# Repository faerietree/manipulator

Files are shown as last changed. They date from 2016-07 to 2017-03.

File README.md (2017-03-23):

Robotic Manipulator
===

The pivot of many machines of the world development global village construction set.

Core
---
* scalable (scale up to use for forest work, as crane or defense herc)
* hydraulic (electrical delivered too little payload for DIY heavy duty transmission)

High Level Overview
---

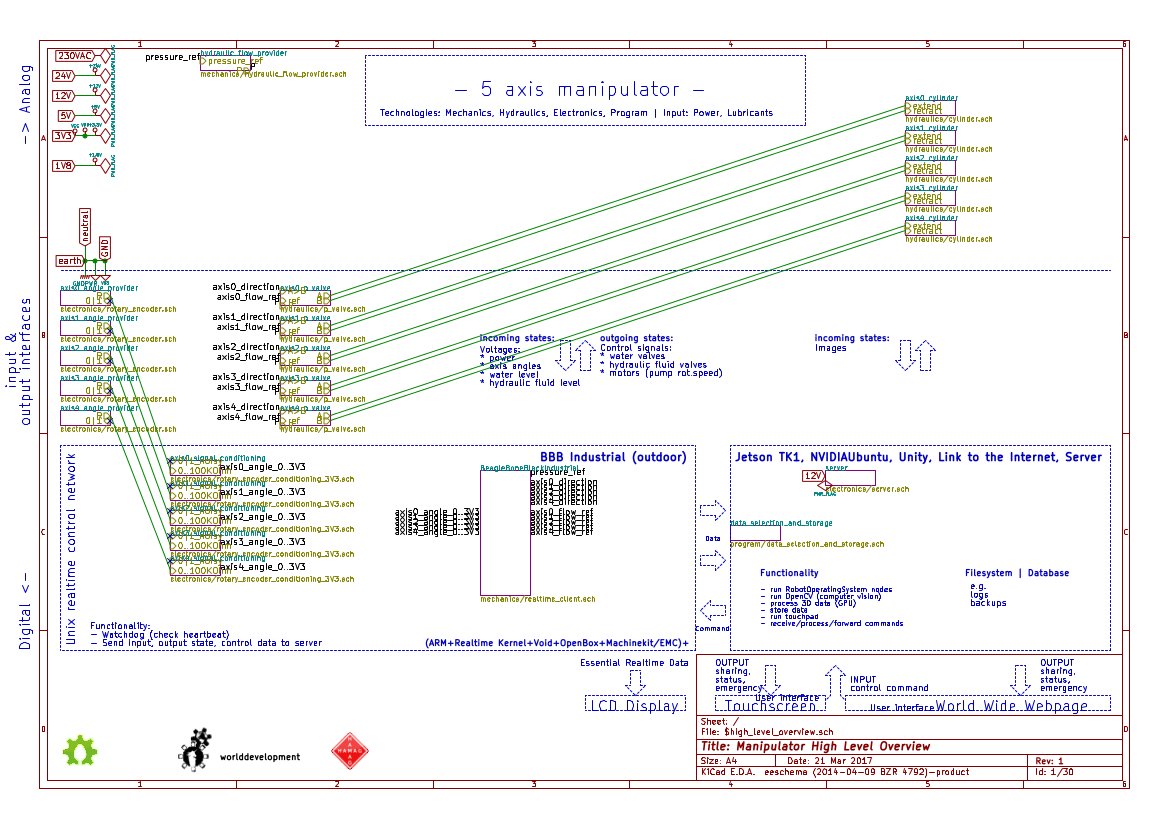
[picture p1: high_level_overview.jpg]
high_level_overview


Developers:
---
worlddevelopment e.V. & other world citizens

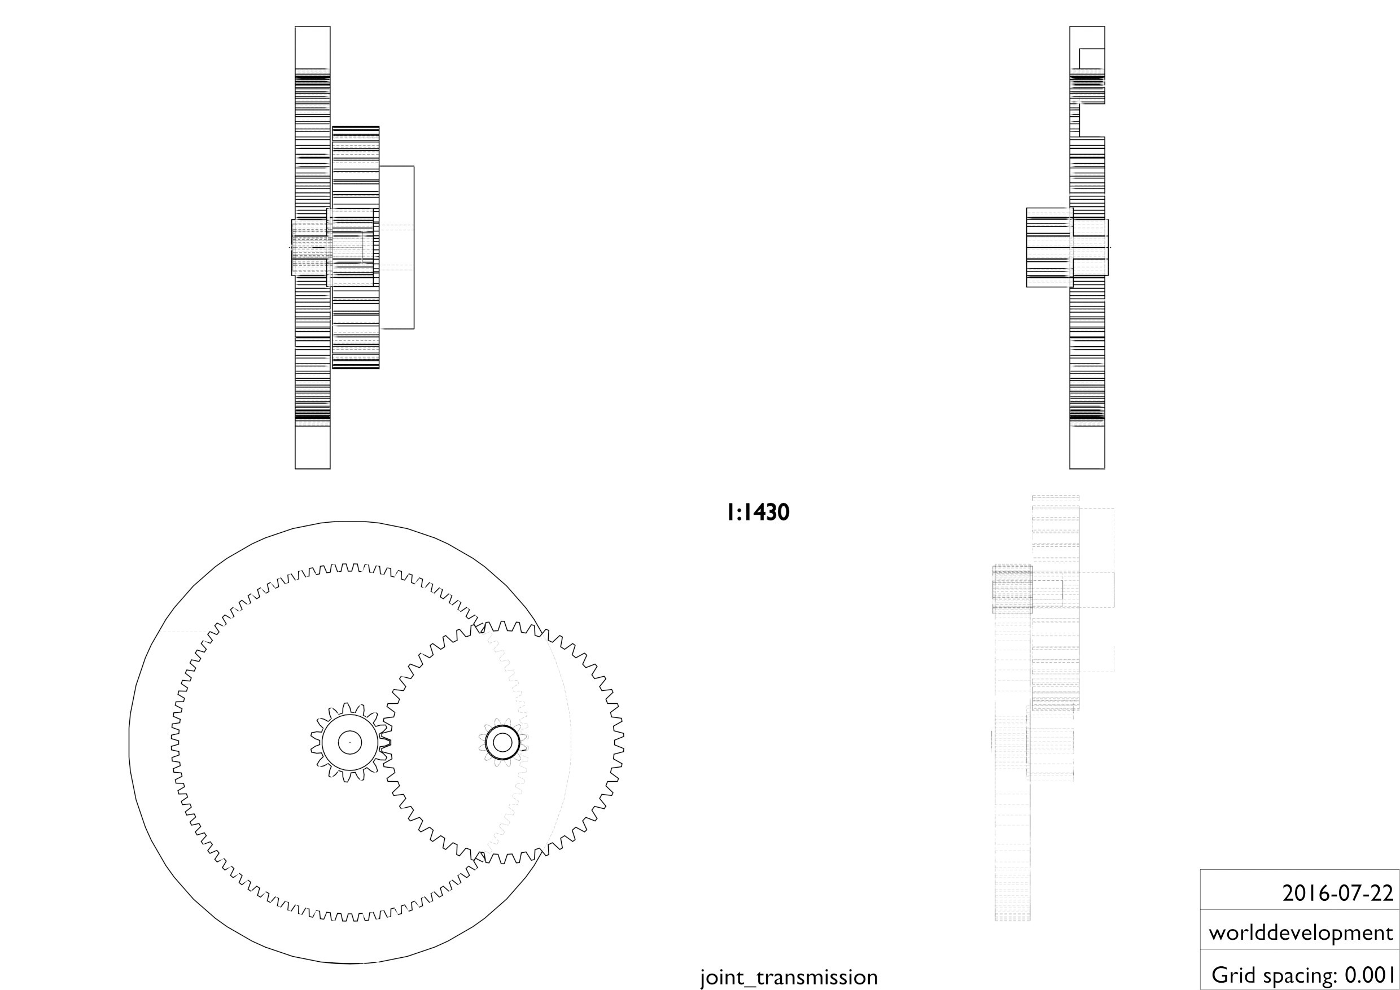
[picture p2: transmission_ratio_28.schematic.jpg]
schematic joint transmission ratio 28


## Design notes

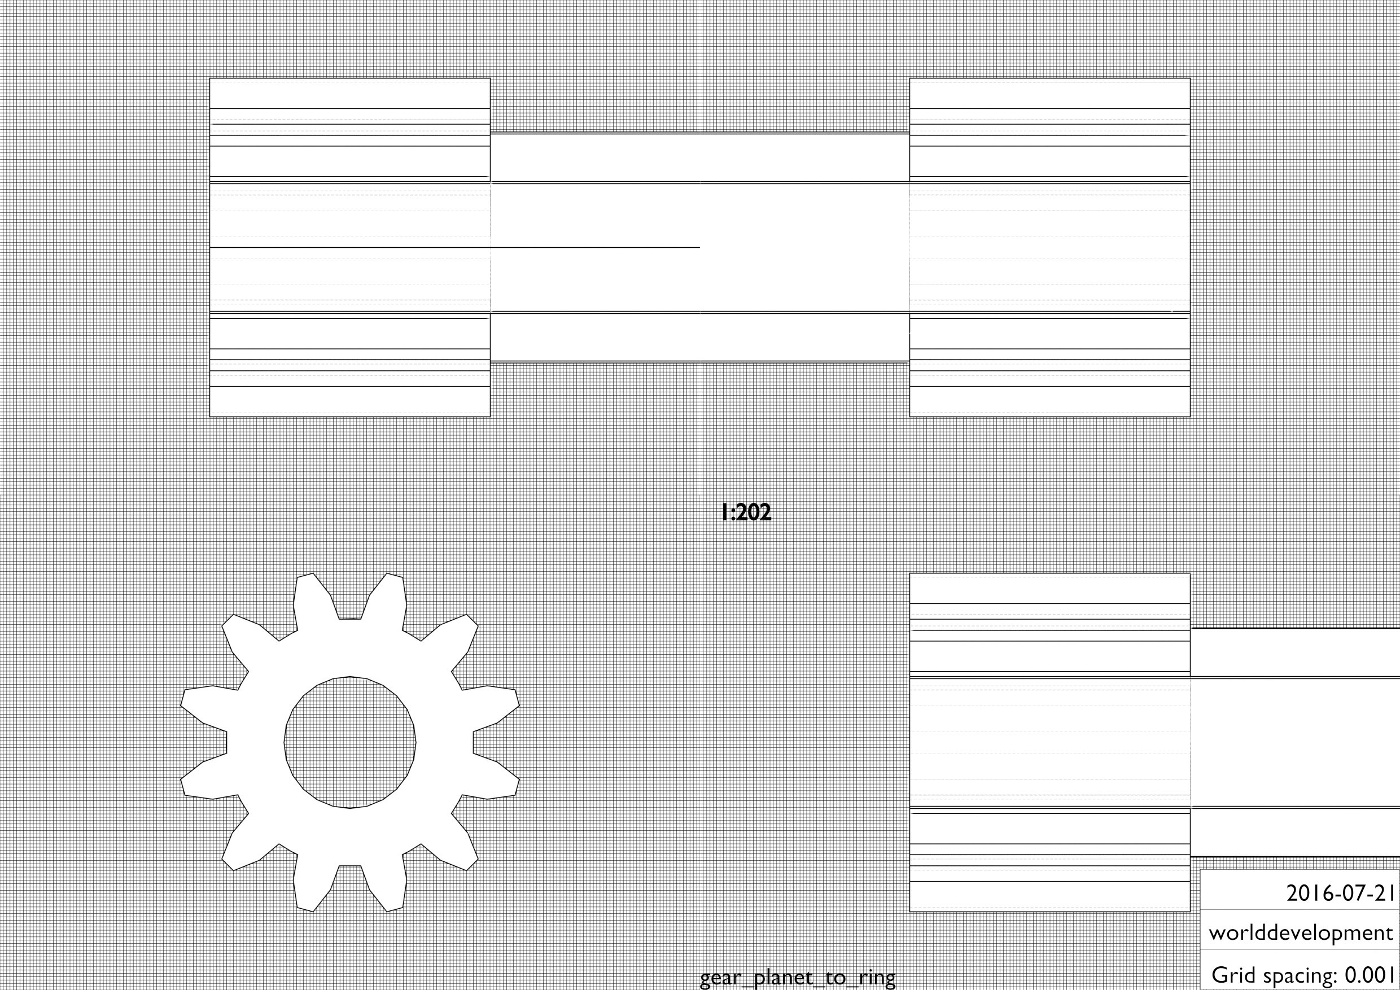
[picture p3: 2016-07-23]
gear_planet_to_ring.schematic.jpg

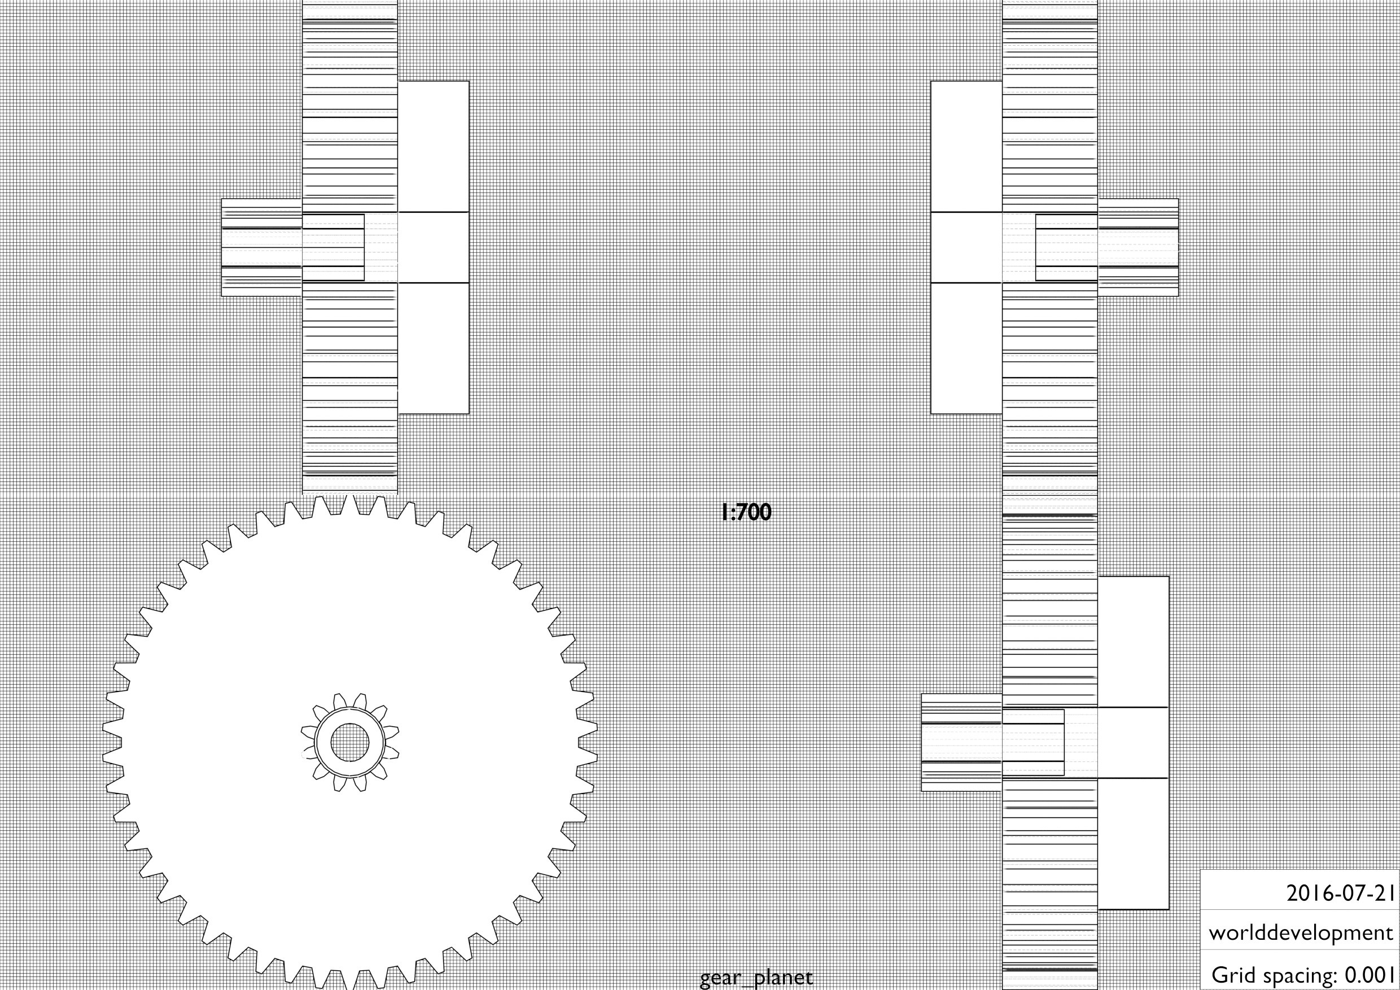
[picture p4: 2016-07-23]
gear_planet.schematic.jpg

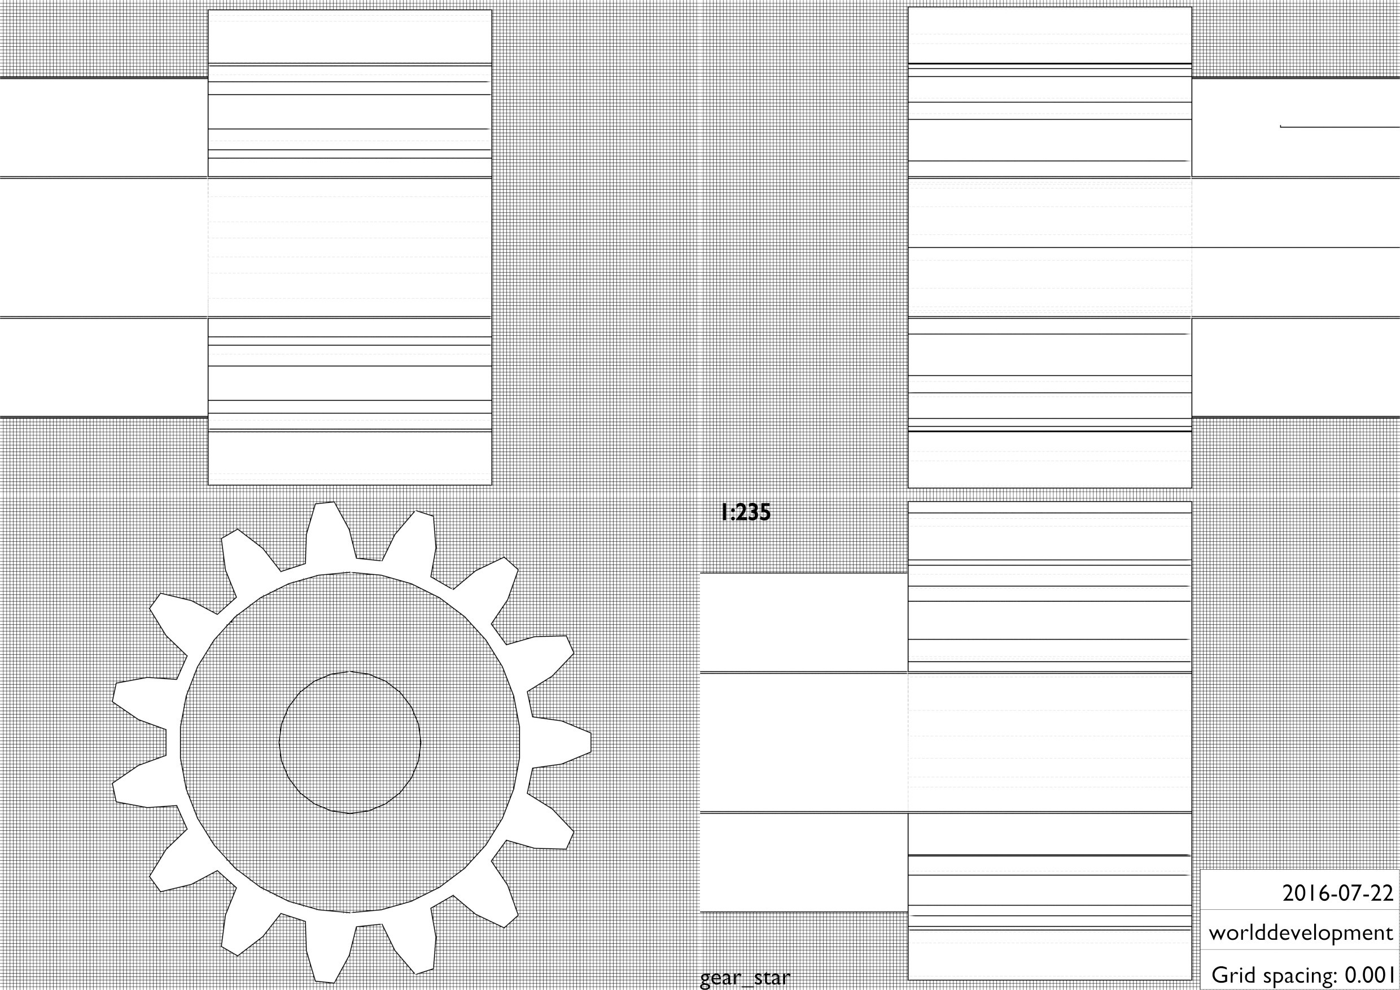
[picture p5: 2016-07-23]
gear_star.schematic.jpg

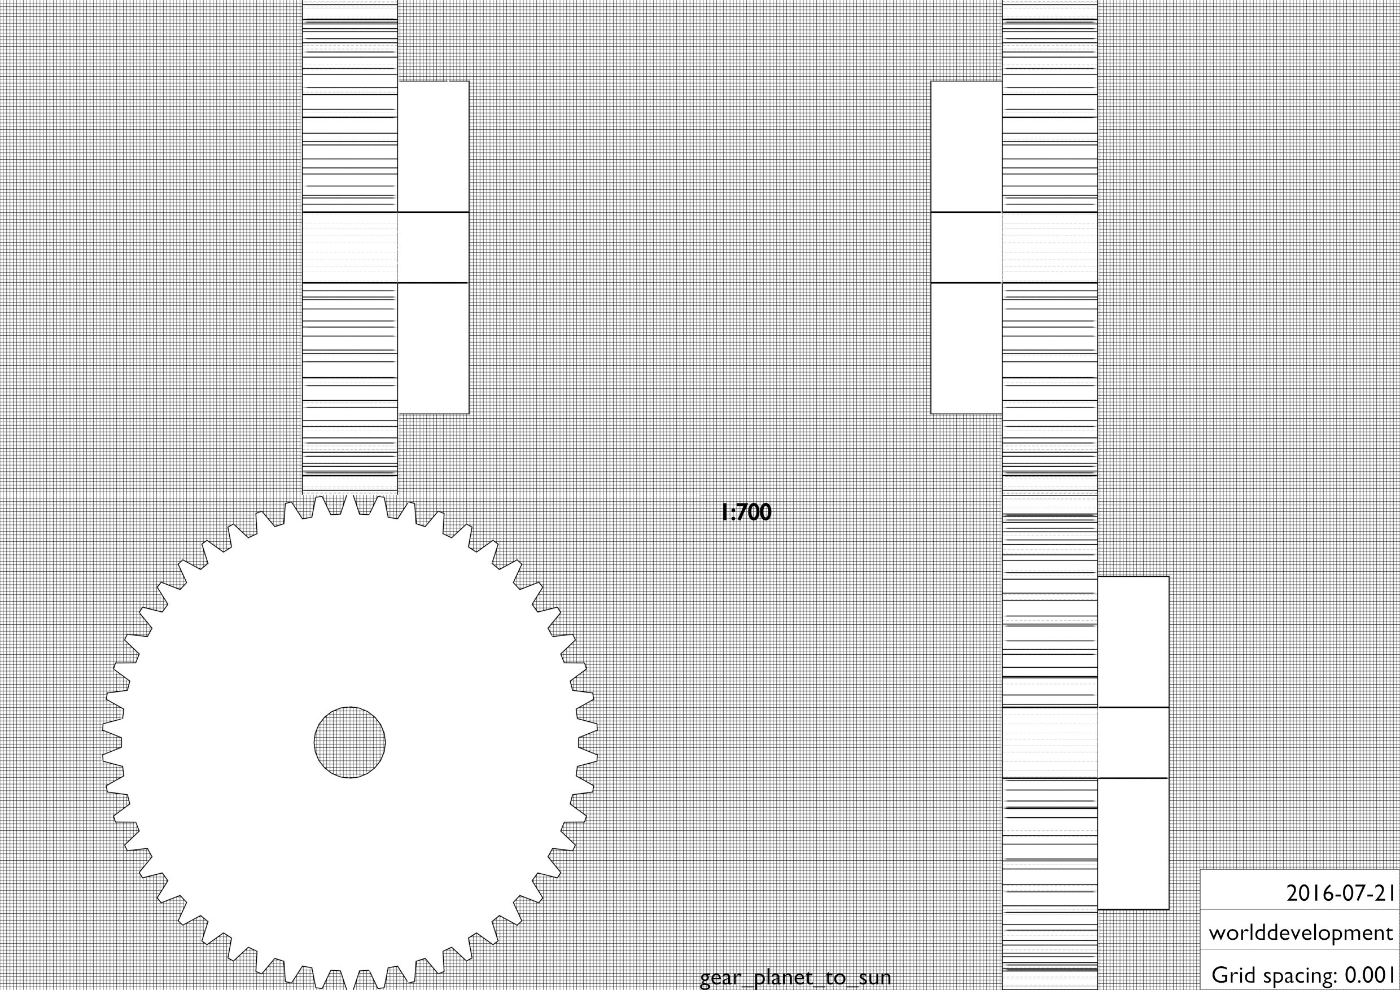
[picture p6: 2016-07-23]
gear_planet_to_sun.schematic.jpg

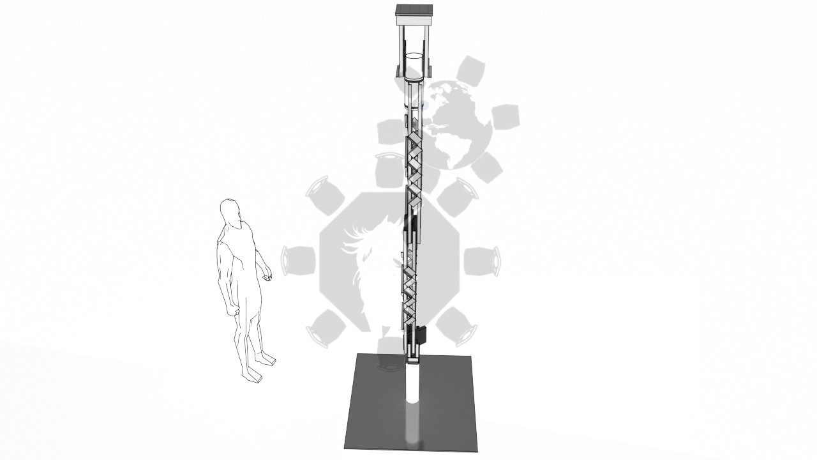
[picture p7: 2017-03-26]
mechanics/manipulator_fountain_pos.jpg

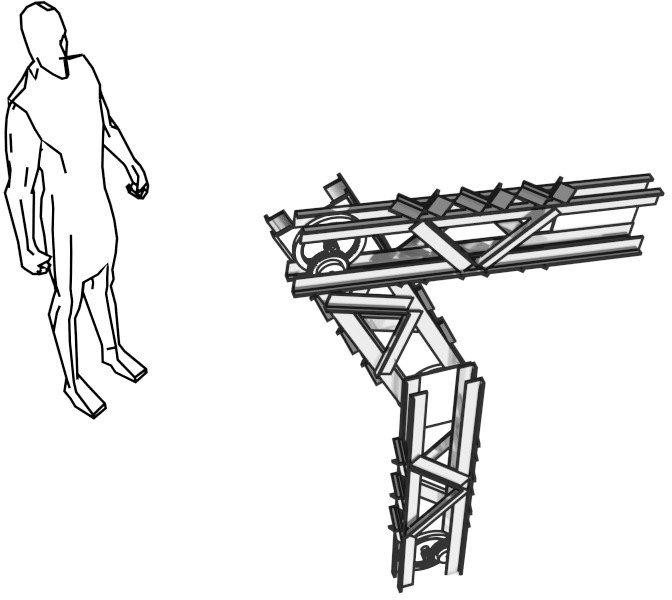
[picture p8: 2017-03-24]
mechanics/manipulator_electric.jpg

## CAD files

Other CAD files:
mechanics/gear.blend
mechanics/gear_pinion.blend
mechanics/gear_ring.blend
mechanics/manipulator.blend
mechanics/motor.blend

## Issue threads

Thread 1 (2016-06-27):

Joint transmission:  Planet gear interfacing ring gear is made of metal instead of plastic leading to erosion.

faerietree, 2016-06-27:
This has the benefit of longer life because this planet gear is in the pinion role leading to more wear because the gear teeth have to more often do more work.

The major disadvantage of it though is that metal to metal contact will lead to immense wear in the shell, i.e. the robotic manipulator links which needs evaluation to check if this makes it the weakest part.

faerietree, 2016-06-27:
* A possible solution is a plastic sheet inbetween the link and the transmission at the corresponding compound gear's side.
* Another idea is to try to source a plastic gear with the same properties at all cost.

Because the manipulator must be as affordable as possible (< 1000 US $) to maximize impact in the world, the first option is the favorite solution.

faerietree, 2017-03-23:
The hydraulic variant, see #4, still has the requirement of reducing metal <-> metal friction. Therefore this issue is still valid for the upcoming hydraulic design.

Closed 2017-03-26.

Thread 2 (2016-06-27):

Joint transmission: Torque is too low, has to lift 20 Kg, lifts only 9 Kg.

faerietree, 2016-06-27:
To ensure speedy design iterations finding a somewhat working hardware configuration, a spreadsheet is used instead of the detailed CFD simulation.

From the first estimations for the joint transmission in the worlddevelopment engineering.ods spreadsheet it became apparent that the current transmission ratio of 15 is too low:
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

faerietree, 2016-06-27:
A new iteration promises a new transmission ratio of approximately 32, results in 21.21 Kg liftable weight, which allows tool + payload to weigh (.5 + .91) Kg = 1.41 Kg.

The permissible payload weight may be higher because the new transmission design uses lighter gears, which is not included in the quick approximation outlined in this comment.

faerietree, 2016-06-27:
Further payload weight may be possible when designing custom links, i.e. either mill out not necessary structural parts (subtraction process, have once done this for quadrotors at university, takes way too long and is not scalable) or by bolting or welding smaller easier cheaper to get metal pieces in an addition process (highly scalable!).

faerietree, 2017-01-03:
Fixed #2 in commit 11f2366 .

Closed 2017-01-03.

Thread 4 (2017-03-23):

Use hydraulics as despite the new - for DIY, heavy duty quite high - transmission ratio of 28, the payload of 12Kg is still to low.

faerietree, 2017-03-23:
Furthermore the hydraulic approach is easily scalable while routing bigger and still matching gears is very problematic, also in terms of link, transmission weight.

Closed 2017-03-26.

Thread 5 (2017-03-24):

Design tool coupling(s) to fit drill, bit chuck, gripper, three point hitch, PTO shaft compatible.

faerietree, 2017-03-24:
see also:
* https://github.com/faerietree/fruit_nut_vegetable_robot/issues/1
* http://opensourceecology.org/wiki/Universal_Rotor

Closed 2017-07-28.

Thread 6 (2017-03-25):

Joint rigidity: Replace the thick plastic sheet with 1 thin metal + 1 plastic sheet.

faerietree, 2017-03-25:
Because the manufacturing possibilities of worlddevelopment are limited (no press, no lathe, no mill, no sheet cutter).

Once the 5 axis manipulator is constructed, then a mill immediately is within reach.

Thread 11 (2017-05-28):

Increase arm segment length to > 1 m to increase radial reach to something more useful.

faerietree, 2017-05-28:
This is a last minute change. Luckily some extra metal has been bought. Let's hope it will suffice for the new segment length of `1.5 m`.

## Reasoning
* Increasing the `maximum radius (pick up) range` to `1.5m + 1.5m + .5m = 3.5m` will result in an effective delta reach of at least `2.5m` (see below).
* Major mount point next to [fruit nut vegetable bot](/faerietree/fruit_nut_vegetable_robot) is [walker](/faerietree/walker) whose [standardized mobile frame](/faerietree/frame) is a square of `3m` if its legs are included. => `1.5m` are lost with and `1m` without legs, resulting in a delta reach of `2.5m` which is plenty compared to the previous `1.5m`.
* An increased `effective radius reach` has more benefits than drawbacks:
   * \+ More things can be lifted as approaching them closer than 2m will seldomly be possible in the wilderness.
  * \+ The manipulator purpose is no longer restricted to just milling or a very small farm field.
  * \+ Area of operation (e.g. caring for food) is `PI * radius^2` which with assumption of min effective reach radius of 3m is `PI * (3m)^2 = approximately 28.5m^2`. Add to this the fruits that are hanging high and there will be quite a nice harvest. (operating space of the manipulator is kind of spherical, i.e. 3D).
  * \- Increasing the segment length will reduce accuracy as long as code, electronics, transmission ratio et alia remain fix.
  * \+ Fewer designs.
  * \+ Less prototypes to build, test.
  * \+ Scale up by factor 2 now results in a reach of `5 m` which is enough for using [walker](/faerietree/walker) as backhoe or forest "harvester" or `harvest crane` or `animal feeder` or `manure remover` or have it help with `construction work` (vertical overall radius is 7m then, see first point of this list).

See why [walker](/faerietree/walker) + [manipulator](/faerietree/manipulator) are the pivot projects of [world developers](/worlddevelopment)? ;-)

Closed 2017-07-28.

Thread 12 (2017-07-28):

Source planet, ring gear, motor combination for rotation of base around Z axis (joint 0)

faerietree, 2017-07-28:
The holding torque has to be met while the Module should be 1.5 due to the low price of the ring gear costing 1/3 of others.

i.e. plastic gears are out of question. likely hardened is required.

Closed 2017-07-28.

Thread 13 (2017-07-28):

Joint 0,1 collide

faerietree, 2017-07-28:
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
Solution: Swap joint 0 motor position with gear, replace ring with gear, increase bearing sheet size.

faerietree, 2017-07-28:
## joint 0 redesign benefits

Luckily the common gear is half as expensive as the ring|internal gear.

Also nice is that the bearing plastic sheet is obsolete now as the gear is made from plastics which also reduces friction with the pinion gear at the motor.

Closed 2017-07-30.

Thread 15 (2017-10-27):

Since 82c2a76 walker legs share the joint mechanics => outsource

faerietree, 2017-10-27:
Delays mechanics prototype because to prevent legal issues no manipulator without [faerietree/walker](walker).

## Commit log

2016-06-26 Estimate the weight the manipulator is able to lift.
    It is seen that the transmission ratio is too low for the given motor
    torque.
    => Redesign planetary transmission.
2016-06-27 Add gear choices of planetary transmission.
    These are dependencies linked as symbolic links - later to be garantueed
    by the worlddevelopment project management tool.
    TODO: Remove the links, instead list in the XML file as dependency once the tool supports this.
    [gear_planet_to_ring.stl, gear_planet_to_sun.stl, gear_ring.stl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]
2016-07-18 Increase transmission ratio to 27.7... Replace STL by BLEND refs.
    Increase transmission ratio to 27.7... = .100/.03 * .150/.018.
    Replace STL by BLEND refs,
    Follow standard
    Ref
    https://github.com/faerietree/multimachine_lightspeed_precise/issues/1
    [gear_planet_to_ring.blend, gear_planet_to_ring.stl, gear_planet_to_sun.blend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]
2016-07-21 Add schematic for ratio 28. Remove ratio 15 images.
2016-07-23 Add schematics for gears used in joint transmission.
2017-01-03 Depict separate payload calculations: 12 Kg payload at 2m. Fix #2
2017-01-03 Depend on gears_maedler module.
2017-01-03 Include dependency file for gear_planet_to_ring.blend.
    As a consequency remove Linux specific symbolic link. Ref #3.
    [gear_planet_to_ring.blend]
2017-01-03 Include dependency file for gear_planet_to_sun.blend.
    As a consequency remove non-crossplatform symbolic link. Ref #3
    [gear_planet_to_sun.blend]
2017-01-03 Include dependency file for gear_ring.blend. Ref #3.
    [gear_ring.blend]
2017-01-03 Include dependency file for gear_star.blend. Fix #3.
    [gear_star.blend]
2017-01-03 Depend on step_motors. Include dependency file for motor.blend.
2017-07-23 Add hydraulic manipulator with base joint using a custom plastic sheet
    of .0095 thickness in conjunction with custom .02 thickness metal plates.
    Fix #4.
    Fix #1 as now every joint is made of plastic <-> metal contact besides
    the joints 0, 3 which have a clearance of .0006 inbetween the two
    metal cylinders of the DIY heavy duty bearing, hardly enough to insert a
    layer of plastic unless a kind of thin tape?
    Fix #5: Add link 4, joint 4 and the tool coupling sheet.
    Add some hydraulic cylinders (not attached).
    [manipulator.blend]
2017-07-28 Add dependencies for joint0. Remove obsolete (those from electric variant).
2017-07-28 Mechanics: Add missing dependency files from the cache (links). Fix #12
    [gear_pinion.blend, gear_ring.blend, motor.blend]
2017-07-28 Mechanics: Fix #11: Add 2m segment hydraulic manipulator. Fix #4.
    layer of plastic unless a kind of thin tape or pouring fluid and let
    it harden.
    Enlarge links'|segments' lengths to 2m.
    Fix #5: Specify link4, joint 4 and the tool coupling sheet.
    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
    [manipulator.blend]
2017-07-28 Swap static, moving cylinder joint 0. Rm hydraulic pump platform.
    Unfortunately joint 0,1 now collide (#13).
    Rm hydraulic pump platform as it is moved inside the hobbit hole to
    reduce noise and thus no longer needed (it's usefulness was questionable
    anyway because the pump can also be located higher at the joint0 sheet
    if the size was increased and it'd remove space and possible depth reach
    as it meant joint 1 had to be placed higher - both on walker and fruit
    nut vegetable gardener).
    [manipulator.blend]
2017-07-30 Mechanics: Update dependencies gear_pinion, gear, motor.
2017-07-30 Mechanics: Renew dependency files (cache).
    [gear.blend, gear_pinion.blend, motor.blend]
2017-07-30 Mechanics: Renew hash after remodelling sorotec motor.
    * shaft was too long
    * double shaft was missing
    * motor body was too short
    Reference was the datasheet.
2017-07-30 Fix #13. Swap joint 0 motor with gear. Simplify design.
    Replaces ring with gear.
    Removes extra bearing sheet as the gear is made of plastic.
    Partly reverts cd03087 (group membership swap: static <-> moving)
    * Luckily the common gear is half as expensive as the ring|internal gear.
    * Also nice is that the bearing plastic sheet is obsolete now as the gear is made from plastics which also reduces friction with the pinion gear at the motor.
    * As the motor becomes static now electricity supply wire twisting is prevented in the new design, too.
    * Another positive side effect is that now there is enough space for the bigger NEMA34 compatible motor, resulting in 5 times as much torque which may be r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
    [manipulator.blend]
